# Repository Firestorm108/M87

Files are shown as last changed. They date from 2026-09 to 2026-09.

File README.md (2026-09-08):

# M87
<h3>A dual-resonant solid state Tesla coil, hitting 170kW peaks</h3>
Screenshot 2026-09-07 at 5 58 11 PM
Assembly_2026-Sep-08_12-16-06AM-000_CustomizedView9614355404

<h1>High Voltage Safety</h1>

** I do not advise anyone to replicate this and do not take any responsibility if you choose to do so. **

** This is an advanced high voltage project, DO NOT REPLICATE! **

** I am not responsible for any damage caused from irresponsibly playing with high voltage. ** 

# PCBs
<h4>There are four custom PCBs in this build. </h4>
<h2>Universal Driver "M87"</h2>
Screenshot 2026-09-06 at 10 52 54 PM
<h2>Optical Interrupter</h2>
Screenshot 2026-09-06 at 11 14 16 PM
<H2>Multi-Mini Capacitor</H2>
Screenshot 2026-09-07 at 6 00 40 PM
<h2>Current Transformers</h2>
Screenshot 2026-09-06 at 10 58 16 PM

# Schematics
<h4>The schematics to each PCB</h4>
<h2>Universal Driver "M87"</h2>
Screenshot 2026-09-07 at 6 30 48 PM

<h2>Optical Interrupter</h2>
Screenshot 2026-09-07 at 6 35 54 PM

<h2>Multi-Mini Capacitor & Current Transformers</h2>
Screenshot 2026-09-07 at 6 37 50 PM
Screenshot 2026-09-07 at 6 39 29 PM

# The Bridge
<h3>This is the main switching part of the coil, if you put aside all the logic, isolation, coils, etc.</h4>
Screenshot 2026-09-07 at 6 04 10 PM
<h4>Mainly, it uses two SKM300GB IGBT half-bridges and four 5000uF 450V capacitors. 
These half-bridges are put together to create a full bridge, while the capacitors are both in series and parallel in a voltage doubler configuration.
This results in a total capacitance of 5000uF and a voltage rating of 900V, with a bus voltage of 340V.</h4>

# Specifications

## Power Supply 
* 0 – 120 VAC through a variac
* 30A Full Bridge Rectifier
* 4x 5000uF 450V capacitors in voltage doubling configuration, and in parallel.
  
## Primary Coil
* 320 mm diameter
* 3/8" diameter copper tubing
* 11 total windings, subject to tuning using a scope.

## MMC (Multi-Mini Capacitor)
* 9 strings in parallel of 2 in series 0.1uF 2kV film capacitors.
* Total Rating: 0.45 µF @ 4000 VDC

## Secondary Circuit
* 6.5" diameter x 2' length
* 2200 turns of 30AWG
* 127 x 620 mm aluminum ducting topload

## Parameters

* **Resonant Frequency:** ~65 – 80 kHz
* **Input Power:** 1800W at 120 VAC @ 15 A (500 A OCD)

# Bill of Materials
<h2>For a more detailed look, check out https://docs.google.com/spreadsheets/d/1DjRxDST9gP6VWVaGONw40nzyh7GYetqo9sDGphOBDtU/edit?usp=sharing</h2>

| **Item** | **Price** | **Link** |
| --- | ---: | --- |
| **LOGIC & DRIVING** | | |
| 20VAC Signal Transformer | $1 | [eBay](https://www.ebay.com/itm/156355734533) |
| 14 Pin IC Sockets x3 | $6 | [AliExpress](https://www.aliexpress.us/item/3256805529241851.html) |
| 8 Pin IC Sockets x3 | $6 | [AliExpress](https://www.aliexpress.us/item/3256805529241851.html) |
| SN74HC14 x2 | $4 | [AliExpress](https://www.aliexpress.us/item/3256806000467098.html) |
| LM311 x2 | $4 | [AliExpress](https://www.aliexpress.us/item/2251832814445271.html) |
| SN74HC74 x2 | $6 | [AliExpress](https://www.aliexpress.us/item/3256807843061608.html) |
| SN74HC08 x2 | $4 | [AliExpress](https://www.aliexpress.us/item/3256806000467098.html) |
| UCC27423 x10 (Gate Driver IC) | $25 | [DigiKey](https://www.digikey.com/en/products/detail/texas-instruments/UCC27423P/603260) |
| TO 263 Heatsinks (w/ Pad) | $8 | [AliExpress](https://www.aliexpress.us/item/3256810406260405.html) |
| Thermal Pad | $2 | [AliExpress](https://www.aliexpress.us/item/3256802090742663.html) |
| UD 1.3 Driver | $35 | [eBay](https://www.ebay.com/itm/126296053530) |
| UD M87 Custom Designed Driver PCB | $80 | JLCPCB |
| 200kHz Oscilloscope (SELF-FUNDED) | N/A | [Amazon](https://www.amazon.com/FNIRSI-DSO152-Handheld-Oscilloscope-Bandwidth/dp/B0FDPYNQBC/) |
| **CURRENT TRANSFORMERS** | | |
| Dual Current Transformer Custom PCB | $4 | JLCPCB |
| Ferrite 77 Cores x4 | $9 | [DigiKey](https://www.digikey.com/en/products/detail/fair-rite-products-corp/5977001401/8599655) |
| 24AWG Solid Core | $8 | [Amazon](https://www.amazon.com/DKARDU-Electrical-Stranded-Color%EF%BC%88Black-Assortment/dp/B09PH2ZDLC/r) |
| KF9500 Screw Terminals 2P | $4 | [AliExpress](https://www.aliexpress.us/item/3256806674476213.html) |
| **GATE DRIVE TRANSFORMER** | | |
| Ferrite 77 (a few) | $2 | [DigiKey](https://www.digikey.com/en/products/detail/fair-rite-products-corp/5977001401/8599655) |
| CAT5 Cable | $10 | [Amazon](https://www.amazon.com/Ethernet-Snagless-Computer-Network-Internet/dp/B0BJNZ71K3/) |
| **INTERRUPTER** | | |
| Custom Optical Interrupter PCB | $70 | JLCPCB |
| 5m Fiber Optic Cable HFBR-RNS005Z | $13 | [DigiKey](https://www.digikey.com/en/products/detail/broadcom-limited/HFBR-RNS005Z/1990489) |
| 9V Batteries | $5 | [Amazon](https://www.amazon.com/XUNIUZERO-9V-Batteries-Detector-Long-Lasting/dp/B0F5HLZMH4) |
| 9V Battery Connector | $3 | [AliExpress](https://www.aliexpress.us/item/3256810332396131.html) |
| 50K Potentiometers | $2 | [AliExpress](https://www.aliexpress.us/item/3256806841285775.html) |
| 10K Potentiometers | $2 | [AliExpress](https://www.aliexpress.us/item/3256806841285775.html) |
| 5K Potentiometers | $2 | [AliExpress](https://www.aliexpress.us/item/3256806841285775.html) |
| ON-OFF-ON Toggle Switches x5 | $3 | [AliExpress](https://www.aliexpress.us/item/3256807979121643.html) |
| **FULL BRIDGE** | | |
| 4.7 Ohm 5W Resistors (Cement) | $3 | [AliExpress](https://www.aliexpress.us/item/3256807607955844.html) |
| 4.7 Ohm 5W Resistors (Wirewound) x2 | $4 | [AliExpress](https://www.aliexpress.us/item/3256806563516146.html) |
| 1.5KE220CA x3 | $7 | [AliExpress](https://www.aliexpress.us/item/3256809640787649.html) |
| 1N5364B 33V Zener Diodes x3 | $6 | [AliExpress](https://www.aliexpress.us/item/3256806214186575.html) |
| 400V 10uF Snubber Film Capacitors x2 | $8 | [AliExpress](https://www.aliexpress.us/item/3256808070998741.html) |
| KBPC3510 FBRs x2 | $4 | [AliExpress](https://www.aliexpress.us/item/3256806258995719.html) |
| 5000uF 450V Capacitors x4 | $55 | [eBay](https://www.ebay.com/itm/327028788973) |
| 25K 100W Wirewound Bleeder Resistors x2 | $4 | [AliExpress](https://www.aliexpress.us/item/3256805970781782.html) |
| SKM300GB Brick Half Bridge IGBTs x2 | $60 | [eBay](https://www.ebay.com/itm/267516067582) |
| Copper Busbars x2 | $37 | [Amazon](https://www.amazon.com/Copper-Thickness-Suitable-Battery-Connection/dp/B0BZCRHCHR) |
| Shorting Clips | $6 | [Amazon](https://www.amazon.com/Insulated-Alligator-Durable-Battery-Electric/dp/B0773JXZT9/) |
| Kapton Tape | $10 | [Amazon](https://www.amazon.com/ELEGOO-Polyimide-Temperature-Resistant-Multi-Sized/dp/B072Z92QZ2/) |
| Large Aluminum Heatsink x2 | $26 | [Amazon](https://www.amazon.com/dp/B07TJY3GKP) |
| **MMC (Multi-Mini-Capacitor)** | | |
| Custom Bleeder PCB | $9 | JLCPCB |
| 0.1uF 2kV Capacitors x4 (2 per string, 9 in parallel) 0.45uF 4kV | $16 | [AliExpress](https://www.aliexpress.us/item/3256802900888178.html) |
| MMC Bleeder Resistor: 1M, 2W x2 | $4 | [AliExpress](https://www.aliexpress.us/item/3256802900888178.html) |
| **Primary Coil** | | |
| 3/8 Inch 25 Feet Copper Tubing | $50 | [Amazon](https://www.amazon.com/BELLA-BAYS-Refrigeration-Seamless-Refrigerators/dp/B0BCQYFXLF) |
| **Secondary Coil** | | |
| 6" x 2' PVC Pipe | $24 | [Amazon](https://www.amazon.com/FT-PVC-DWV-SCH-PIPE/dp/B0FFCNLJLH/) |
| 3lbs 30AWG Magnet Wire | $55 | [Amazon](https://www.amazon.com/MECCANIXITY-Enameled-Magnetic-Transformer-Fahrenheit/dp/B0FK92B2VT/r) |
| **Topload** | | |
| 8" x 25' Aluminum Flex Tube | $35 | [Amazon](https://www.amazon.com/VIVOSUN-Non-Insulated-Aluminum-Ventilation-Stainless/dp/B010UCCR3A/) |
| **Strike Ring** | | |
| 9AWG Aluminum Wire | $10 | [Amazon](https://www.amazon.com/Tenn-Well-Aluminum-Bendable-Sculpting/dp/B095Y8N92C) |
| **Frame / Misc.** | | |
| 500mm Extrusions x4 | N/A | Already Owned |
| 300mm Extrusions x8 | N/A | Already Owned |
| 2020 Corner Brackets x24 | N/A | Already Owned |
| 500mmx300mmx3mm ABS Sheet | $34 | [Amazon](https://www.amazon.com/Plastic-Styrene-Sheets-Building-Crafts/dp/B0GS4NB2Y3) |
| Tin Snips | N/A | Already Owned |
| **SHIPPING & TAX (KMS)** | | |
| JLCPCB Shipping | $105 | Sob |
| Tax | $100 | |
| **Total** |  **$992** | |

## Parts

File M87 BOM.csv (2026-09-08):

Item | Price | Link
LOGIC & DRIVING
20VAC Signal Transformer | $1 | https://www.ebay.com/itm/156355734533
14 Pin IC Sockets x3 | $6 | https://www.aliexpress.us/item/3256805529241851.html
8 Pin IC Sockets x3 | $6 | https://www.aliexpress.us/item/3256805529241851.html
SN74HC14 x2 | $4 | https://www.aliexpress.us/item/3256806000467098.html
LM311 x2 | $4 | https://www.aliexpress.us/item/2251832814445271.html
SN74HC74 x2 | $6 | https://www.aliexpress.us/item/3256807843061608.html
SN74HC08 x2 | $4 | https://www.aliexpress.us/item/3256806000467098.html
UCC27423 x10 (Gate Driver IC) | $25 | https://www.digikey.com/en/products/detail/texas-instruments/UCC27423P/603260
TO 263 Heatsinks (w/ Pad) | $8 | https://www.aliexpress.us/item/3256810406260405.html
Thermal Pad | $2 | https://www.aliexpress.us/item/3256802090742663.html
UD 1.3 Driver | $35 | https://www.ebay.com/itm/126296053530
UD M87 Custom Designed Driver PCB | $80 | JLCPCB
200kHz Oscilloscope (SELF-FUNDED) | N/A | https://www.amazon.com/FNIRSI-DSO152-Handheld-Oscilloscope-Bandwidth/dp/B0FDPYNQBC/
CURRENT TRANSFORMERS
Dual Current Transformer Custom PCB | $4 | JLCPCB
Ferrite 77 Cores x4 | $9 | https://www.digikey.com/en/products/detail/fair-rite-products-corp/5977001401/8599655
24AWG Solid Core | $8 | https://www.amazon.com/DKARDU-Electrical-Stranded-Color%EF%BC%88Black-Assortment/dp/B09PH2ZDLC/r
KF9500 Screw Terminals 2P | $4 | https://www.aliexpress.us/item/3256806674476213.html?
GATE DRIVE TRANSFORMER
Ferrite 77 (a few) | $2 | https://www.digikey.com/en/products/detail/fair-rite-products-corp/5977001401/8599655
CAT5 Cable | $10 | https://www.amazon.com/Ethernet-Snagless-Computer-Network-Internet/dp/B0BJNZ71K3/
INTERRUPTER
Custom Optical Interrupter PCB | $70 | JLCPCB
5m Fiber Optic Cable HFBR-RNS005Z | $13 | https://www.digikey.com/en/products/detail/broadcom-limited/HFBR-RNS005Z/1990489
9V Batteries | $5 | https://www.amazon.com/XUNIUZERO-9V-Batteries-Detector-Long-Lasting/dp/B0F5HLZMH4
9V Battery Connector | $3 | https://www.aliexpress.us/item/3256810332396131.html
50K Potentiometers | $2 | https://www.aliexpress.us/item/3256806841285775.html
10K Potentiometers | $2 | https://www.aliexpress.us/item/3256806841285775.html
5K Potentiometers | $2 | https://www.aliexpress.us/item/3256806841285775.html
ON-OFF-ON Toggle Switches x5 | $3 | https://www.aliexpress.us/item/3256807979121643.html
FULL BRIDGE
4.7 Ohm 5W Resistors (Cement) | $3 | https://www.aliexpress.us/item/3256807607955844.html
4.7 Ohm 5W Resistors (Wirewound) x2 | $4 | https://www.aliexpress.us/item/3256806563516146.html?
1.5KE220CA x3 | $7 | https://www.aliexpress.us/item/3256809640787649.html
1N5364B 33V Zener Diodes x3 | $6 | https://www.aliexpress.us/item/3256806214186575.html
400V 10uF Snubber FIlm Capacitors x2 | $8 | https://www.aliexpress.us/item/3256808070998741.html
KBPC3510 FBRs x2 | $4 | https://www.aliexpress.us/item/3256806258995719.html
5000uF 450V Capacitors x4 | $55 | https://www.ebay.com/itm/327028788973
25K 100W Wirewound Bleeder Resistors x2 | $4 | https://www.aliexpress.us/item/3256805970781782.html
SKM300GB Brick Half Bridge IGBTs x2 | $60 | https://www.ebay.com/itm/267516067582
Copper Busbars x2 | $37 | https://www.amazon.com/Copper-Thickness-Suitable-Battery-Connection/dp/B0BZCRHCHR
Shorting Clips | $6 | https://www.amazon.com/Insulated-Alligator-Durable-Battery-Electric/dp/B0773JXZT9/
Kapton Tape | $10 | https://www.amazon.com/ELEGOO-Polyimide-Temperature-Resistant-Multi-Sized/dp/B072Z92QZ2/
Large Aluminum Heatsink x2 | $26 | https://www.amazon.com/dp/B07TJY3GKP
MMC (Multi-Mini-Capacitor)
Custom Bleeder PCB | $9 | JLCPCB
0.1uF 2kV Capacitors x4 (2 per string, 9 in parallel) 0.45uF 4kV | $16 | https://www.aliexpress.us/item/3256802900888178.html
MMC Bleeder Resistor: 1M, 2W x2 | $4 | https://www.aliexpress.us/item/3256802900888178.html
Primary Coil
3/8 Inch 25 Feet Copper Tubing | $50 | https://www.amazon.com/BELLA-BAYS-Refrigeration-Seamless-Refrigerators/dp/B0BCQYFXLF
Secondary Coil
6" x 2' PVC Pipe | $24 | https://www.amazon.com/FT-PVC-DWV-SCH-PIPE/dp/B0FFCNLJLH/
3lbs 30AWG Magnet Wire | $55 | https://www.amazon.com/MECCANIXITY-Enameled-Magnetic-Transformer-Fahrenheit/dp/B0FK92B2VT/r
Topload
8" x 25' Aluminum Flex Tube | $35 | https://www.amazon.com/VIVOSUN-Non-Insulated-Aluminum-Ventilation-Stainless/dp/B010UCCR3A/
Strike Ring
9AWG Aluminum Wire | $10 | https://www.amazon.com/Tenn-Well-Aluminum-Bendable-Sculpting/dp/B095Y8N92C
Frame / Misc.
500mm Extrusions x4 | N/A | Already Owned
300mm Extrusions x8 | N/A | Already Owned
2020 Corner Brackets x24 | N/A | Already Owned
500mmx300mmx3mm ABS Sheet | $34 | https://www.amazon.com/Plastic-Styrene-Sheets-Building-Crafts/dp/B0GS4NB2Y3
Tin Snips | N/A | Already Owned
SHIPPING & TAX (KMS)
JLCPCB Shipping | $105 | Sob
Tax | $100
Total | $992

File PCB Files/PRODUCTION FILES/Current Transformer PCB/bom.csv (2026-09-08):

Designator | Footprint | Quantity | Value | LCSC Part #
J1 | CONN-TH_2P-P9.50_HB9500-9.5-2P | 1 | Feedback CT | C60785
J2 | CONN-TH_2P-P9.50_HB9500-9.5-2P | 1 | OCD CT | C60785
TR1 | Transformer_Zeming_ZMCT103C | 1 | Feedback CT
TR3 | Transformer_Zeming_ZMCT103C | 1 | OCD CT
TR4 | Transformer_Zeming_ZMCT103C | 1 | Primary CT

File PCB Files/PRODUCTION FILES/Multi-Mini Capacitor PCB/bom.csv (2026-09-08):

Designator | Footprint | Quantity | Value | LCSC Part #
C1, C10, C11, C12, C13, C14, C15, C16, C17, C18, C2, C3, C4, C5, C6, C7, C8, C9 | C_Rect_L29.0mm_W7.6mm_P27.50mm_MKT | 18 | 0.1uF 2kV
J1 | CONN-TH_P10.16_KF135T-10.16-2P | 1 | MMC | C475108
R1, R10, R11, R12, R13, R14, R15, R16, R17, R18, R2, R3, R4, R5, R6, R7, R8, R9 | R_Axial_DIN0414_L11.9mm_D4.5mm_P20.32mm_Horizontal | 18 | 1M 2W

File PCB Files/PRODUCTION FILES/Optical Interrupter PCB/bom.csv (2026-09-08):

Designator | Footprint | Quantity | Value | LCSC Part #
AV1 | CONN-TH_AV-5 | 1 | AV-5 | C18080
C1 | 0603 | 1 | 1uF
C10, C12, C8 | 0603 | 3 | 100nF
C11, C14, C16, C2, C6, C9 | 0603 | 6 | 10nF
C13 | 0603 | 1 | 22nF
C15 | 0603 | 1 | 47nF
C17, C3, C4, C5 | 0603 | 4 | 0.1uF
C7 | 0603 | 1 | 10uF
D1, D2, D3 | D_SOD-123 | 3 | 1N4148W
J1 | CONN-TH_P10.16_KF135T-10.16-2P | 1 | 9V BATTERY | C475108
Q2, Q3 | SOT-23 | 2 | BC847
R1, R10, R11, R13, R3 | 0603 | 5 | 1K
R12, R9 | 0603 | 2 | 100
R14 | 0603 | 1 | 10K
R15, R16 | 2512 | 2 | 220 1W
R2 | 0603 | 1 | 6.8K
R4 | 0603 | 1 | 100K
R6, R7 | 0603 | 2 | 2.2K
R8 | 0603 | 1 | 22K
RV1 | Potentiometer_Alps_RK163_Single_Horizontal | 1 | 10K
RV2, RV3, RV4 | Potentiometer_Alps_RK163_Single_Horizontal | 3 | 50K
RV5 | Potentiometer_Alps_RK163_Single_Horizontal | 1 | 5K
SW1 | PinHeader_1x02_P2.54mm_Vertical | 1 | BURST
SW2 | PinHeader_1x02_P2.54mm_Vertical | 1 | Stable Switch
SW3 | PinHeader_1x02_P2.54mm_Vertical | 1 | Burst Switch
SW4 | PinHeader_1x02_P2.54mm_Vertical | 1 | Music_Switch
U1 | SOP-8_L4.9-W3.9-P1.27-LS6.0-BL | 1 | LM741 | C5145278
U2, U3, U4, U5 | SOIC-8_3.9x4.9mm_P1.27mm | 4 | NE555D
U6, U7 | CONN-TH_HFBR-1521Z | 2 | HFBR-1521Z | C188712

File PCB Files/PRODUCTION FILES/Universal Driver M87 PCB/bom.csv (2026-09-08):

Designator | Footprint | Quantity | Value | LCSC Part #
C1, C2, C22, C3 | 1206 | 4 | 100uF
C10, C11, C12, C15, C20, C4, C5, C8, C9 | 0603 | 9 | 0.1uF
C13 | 0603 | 1 | 22nF
C14 | 0603 | 1 | 1uF
C16, C17, C18, C21 | 0603 | 4 | 10uF
C6, C7 | 0603 | 2 | 1nF
D1 | 0805 | 1 | POWER
D10, D11, D4, D6, D8, D9 | D_SMA | 6 | SS14
D12 | 0805 | 1 | INTERRUPTER
D13 | 0805 | 1 | OVERCURRENT DETECTION
D14, D15, D16, D2, D7 | D_SOD-123 | 5 | 1N4148W
D17, D18 | SMB_L4.3-W3.6-LS5.2-RD | 2 | SMBJ5337B | C545278
FC1 | COMM-TH_HFBR_2521ETZ | 1 | HFBR-2521Z | C188716
J1 | CONN-TH_P10.16_KF135T-10.16-2P | 1 | 20VAC | C475108
J2 | CONN-TH_P10.16_KF135T-10.16-2P | 1 | Feedback CT | C475108
J3 | CONN-TH_P10.16_KF135T-10.16-2P | 1 | OCD CT | C475108
J4 | CONN-TH_P10.16_KF135T-10.16-2P | 1 | GDT | C475108
Q1, Q2 | TO-263-2 | 2 | IRF9540
Q4, Q7 | TO-263-2 | 2 | IRF540
R1, R11, R2, R4, R5, R9 | 0603 | 6 | 1K
R10 | 0603 | 1 | 10
R3 | 1812 | 1 | 10
R6, R7 | 0603 | 2 | 470
R8 | 0603 | 1 | 20K
RV1 | RES-ADJ-TH_3296W | 1 | 10K | C60620
U1 | HBS_4P-L10.2-W7.2-P5.50-LS10.0-BR | 1 | HBS1010 | C22447883
U2 | DIP-14_W7.62mm | 1 | 74HC14
U3 | DIP-8_W7.62mm | 1 | LM311
U4 | TO-263-2 | 1 | L7824
U5 | TO-263-2 | 1 | L7805
U6 | TO-263-2 | 1 | L7809
U7 | DIP-14_W7.62mm | 1 | 74HC74
U8 | DIP-14_W7.62mm | 1 | 74HC08
U9 | DIP-8_W7.62mm | 1 | ~

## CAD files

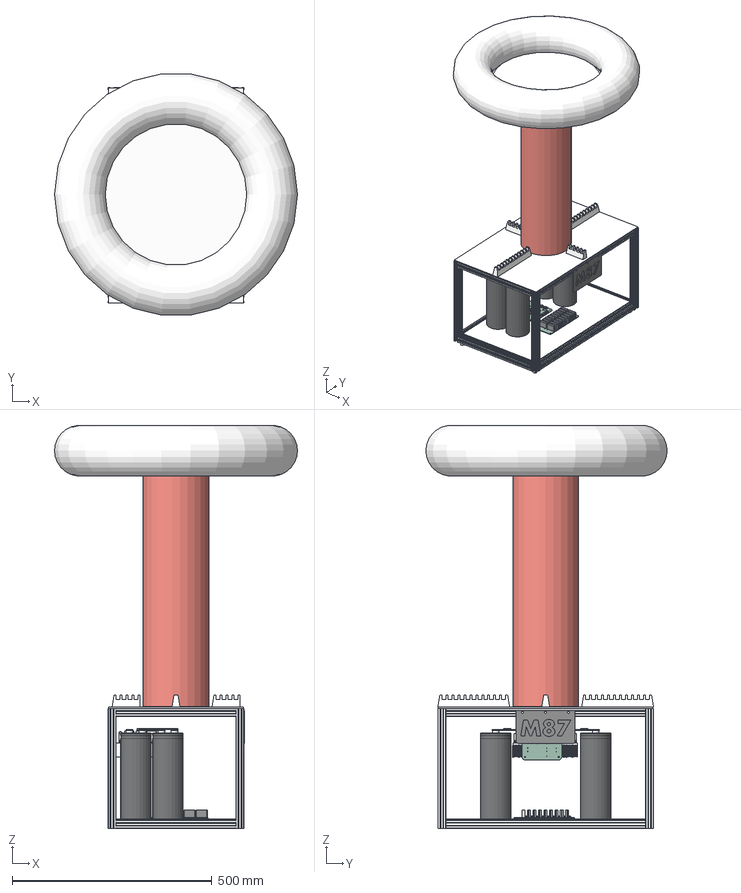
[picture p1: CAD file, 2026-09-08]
CAD/Assembly_step.step
608.0 x 603.6 x 1023.3 mm
99437A165 x 6
D_SOD-123_5 x 5
LED_0805_2012Metric_3 x 3
C_0603_1608Metric_17 x 17
D_SMA_6 x 6
R_0603_1608Metric_10 x 10
C_1206_3216Metric_4 x 4
a3dd6ad7-9c39-11ed-93f0-dde97e994e83_part x 7
a3dd6ad8-9c39-11ed-93f0-dde97e994e83_part x 7
a3dd6ad9-9c39-11ed-93f0-dde97e994e83_part x 7
DIP-8_W7.62mm_2 x 2
DIP-14_W7.62mm_3 x 3
R_1812_4532Metric_1
UD_M87_PCB
R_Axial_DIN0414_L119mm_D45mm_P2032mm_Horizontal x 18
C_Rect_L290mm_W76mm_P2750mm_MKT x 18
MMC_PCB
CurrentTransformers_PCB

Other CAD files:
CAD/Assembly_f3z.f3z

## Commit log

2026-09-08 Add Multi-Mini Capacitor section to README
2026-09-08 Rename M87 BOM - Sheet1.csv to M87 BOM.csv
    [M87 BOM.csv]
